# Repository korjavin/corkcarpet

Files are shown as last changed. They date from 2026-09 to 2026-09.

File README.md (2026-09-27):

# Corkcarpet — 3D-Printed Wine Cork Shower Mat

On Thingiverse: https://www.thingiverse.com/thing:7415303

A massage shower mat made from ~100 natural wine corks. The corks stand vertically inside a 3D-printed interlocking frame. Only the corks touch the floor — the plastic frame floats 5 mm above the floor, supported entirely by the corks.

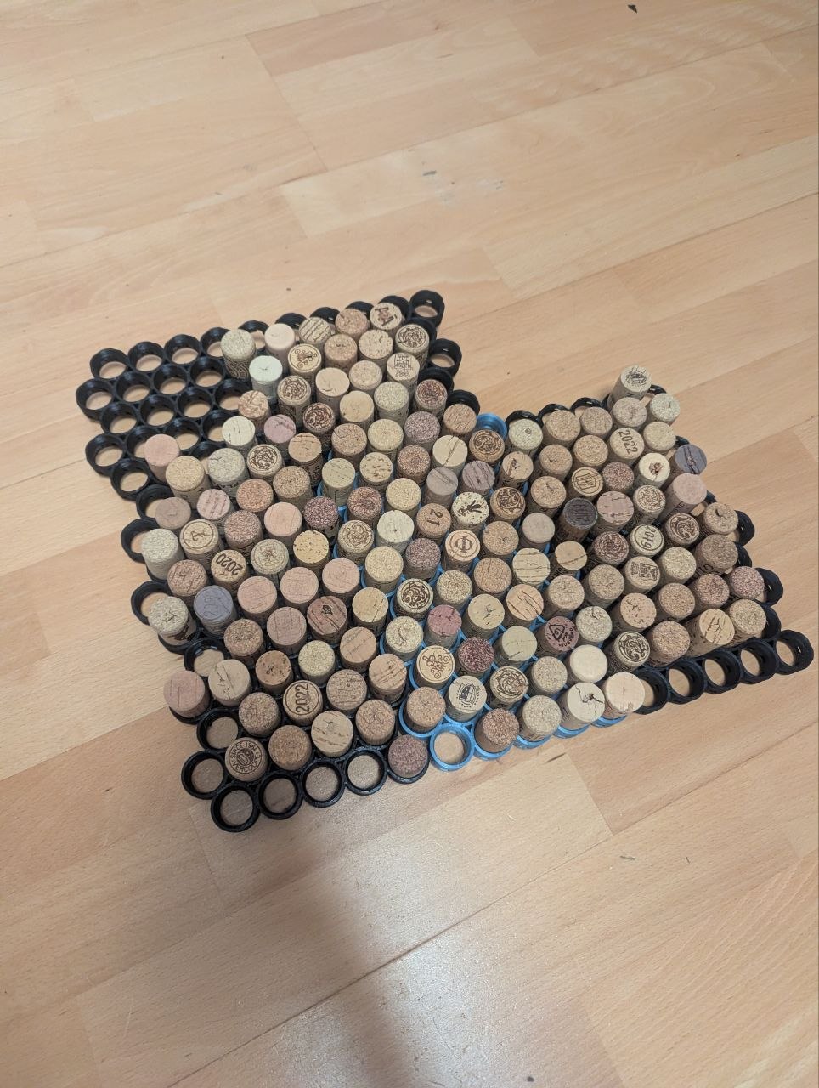
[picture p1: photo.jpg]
Assembled Corkcarpet


## What to Print

For a standard 100-cork mat (approx. 275 × 215 mm) made of 4 tiles:

| File | Quantity | Description |
|---|---|---|
| `tile_5x5_hex.stl` | 4 | 25-socket tile (137.5 × 112.6 × 15 mm, ~82 g PLA). Edge cups are trimmed along the hex cell boundary so tiles nest flush and all tunnels align perfectly. |
| `small_parts_plate.stl` | 1 | Convenience plate containing 12 dowels + 3 spacers in a single 74 × 66 mm print (~20 min). |
| *or* `dowel.stl` | 12 | 4 × 4 × 8 mm square dowel to lock tiles together (printed individually). |
| *or* `spacer.stl` | 3 | 5 mm height spacer, used only during assembly to set the bottom cork offset. |
| `dowel_thin.stl` | Optional | 8 × 3.4 × 4 mm thin dowel — use if the standard 4 × 4 dowel is too tight in your printed tunnels. |
| `dowel_wedge_x12.stl` | Optional (1) | 12 tapered wedge dowels (2 → 5 mm × 10 mm) in one print, printed lying flat. Useful if 3D-printed tunnel ceilings sag and standard square dowels fit too tightly. |

### Cork Fit Test & Training Set (print this first)

`test_tubes.stl` — 7 sockets with bore Ø18.5 … 21.5 mm in 0.5 mm steps (no supports, same orientation as the tile). A notch marks the Ø18.5 end; sizes then go up in a zigzag between the two rows: 18.5, 19.0, 19.5, 20.0, 20.5, 21.0, 21.5.

How to use it:
1. Print it with the same material and profile you will use for the tiles.
2. Press a few typical corks (narrow end down) into each socket. The right size holds the cork firmly by friction but still lets you push it through with your thumb.
3. The tiles are built with Ø20.0. If a different socket fits your corks and printer best, set `SOCKET_D` in `build_tile.py` to that value and regenerate the tile in Blender.
4. Keep the print as a sorting gauge: a cork that drops through Ø20.0 by itself is too thin, one that won't enter Ø21.5 is too thick.

**Training corks before assembly.** The same print is a cork "trainer". A fresh cork is stiff and hard to press into a Ø20 tile socket. Push it through the sockets one by one, from the widest (Ø21.5) down to Ø20.0 (or one step smaller). Each step squeezes the cork a little; after the run it slides into the tile easily and still expands enough to grip. Train a batch of corks right before you press them into the mat.

### Slicing & Printing Recommendations
- **Cura profiles**: Included in the `cura/` folder — import `cura/CorkMat_PLA_Fast.curaprofile` (or `cura/CorkMat_PETG_Fast.curaprofile` for PETG) via *Preferences → Profiles → Import*.
- **Tile orientation**: Print flat with socket entry funnels facing down (as exported). No supports needed.
- **Print order**: Print small parts first (~20 min) to test tolerances, then the tiles (~7 hrs each with Fast profile).

## Cork Selection

- **Type**: Solid, natural wine corks with a narrow end of 20–21 mm. Discard corks that are too thin (<20 mm) or too thick (>21.5 mm at the narrow end).
- **Length**: 45–49 mm is typical and works well; length variance does not affect the assembly.

## Assembly

1. **Arrange Tiles**: Place 4 tiles on a flat surface in a 2 × 2 grid. Rotate the top row of tiles by 180° so the staggered hexagonal pattern and interlocking seams mesh together.
2. **Insert Dowels**: On each of the four seams, choose 3 pairs of adjacent socket cups (e.g. both ends and the middle). At 2 mm above the bottom of the cup wall, there is a square tunnel leading into the adjacent socket. Push a 4 × 4 × 8 mm dowel through the tunnel from inside one cup until it spans both walls and protrudes ~1 mm into each socket.
3. **Place Spacers**: Slide 2–3 spacers (5 mm thick) under the frame so the plastic floats above the table.
4. **Press Corks**: Insert corks narrow end down into the socket entry funnel and press down firmly until the cork touches the table. The cork will protrude exactly 5 mm below the bottom of the frame, locking the dowels securely in place. Start with the sockets that contain dowels to lock them first.
5. **Finish**: Remove the spacers. The mat is ready to use!

## Disassembly

To separate tiles, pull out the corks from the sockets containing dowels, push the dowels out, and detach the tiles.

## Care & Maintenance

Natural cork is water-resistant and mold-resistant. Every few months, shake out the mat and let it air-dry. If an individual cork becomes loose over time, simply replace it with a slightly thicker one.

## License

CC BY 4.0 — Creative Commons Attribution 4.0 International.

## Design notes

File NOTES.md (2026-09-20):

# Corkcarpet — коврик для душа из винных пробок

Статус на 2026-09-10: калибровка сделана (PLA). SOCKET_D = 20.0 (средний из ряда трёх, штангенциркуль 20.0, принтер печатает в размер). tile_5x5.stl экспортирован с 20.0. Следующее: печать плитки из PETG.

## Идея
~100 натуральных винных пробок стоят вертикально в 3D-печатном держателе. Массажный коврик для душа:
нога стоит на пробке, пластик низко, никакой верхней плиты. Рамка ВИСИТ на пробках: пробка держится
трением узким концом вниз, проходит сквозь стакан и выступает на 5 мм НИЖЕ пластика — пола касаются
только пробки (пластик царапал поддон, пробка не скользит и не царапает). Упора нет: широкий конец
пробки сам не проходит через Ø20. Дренаж свободный, рамка над полом.

## Замеры пробок (4 шт.)
- узкий конец 20–21 мм, широкий 20–23 мм, длина 45–49 мм
- пробок много, аутлайеры отбраковываем, сортируем

## Решения
- Раскладка: гексагональная (шахматная), шаг 25 мм → зазор между пробками ~2 мм
- Плитка 5×5 = 25 гнёзд, 138.5×112.6×15 мм; 4 плитки = 100 гнёзд, коврик ~277×217 мм. Второй ряд плиток кладётся повёрнутым на 180° (нечётное число рядов), файл один.
- Стакан Ø26 снаружи, стаканы перекрываются на 1 мм (шов 7 мм) — это и есть каркас
- Стакан 15 мм: конусный заход 5 мм (Ø22.5 → Ø20) + сквозной цилиндр Ø20 на 10 мм. Без упора, без арок. Туннели 4.4×4.4 через стенки на z=2..6.4 в 3 направлениях (под шпонки).
- Материал коврика: PETG (душ, тёплая вода; PLA поведёт). Тест — на PLA, это ок.
- Принтер: Creality Ender, стол 220×220 (уточнить модель), слайсер Ultimaker Cura
- Multiboard Octagon Plate.stl — референс (решётка, фаски, идея соединителей), геометрию не берём

## Файлы
- `corkcarpet.blend` — сцена: tile, cork_* (макет пробок), test_tubes, test2_plate, test_plate, multiboard_ref
- `build_tile.py` — генератор: `build()` плитка, `build_test()` калибровка. Все размеры в шапке,
  `SOCKET_D` — посадочный диаметр, единственная неизвестная. Запуск: exec в Blender (через blender-mcp
  сокет localhost:9876, execute_code) или в текстовом редакторе Blender.
- `tile_5x5_hex.stl` — ТЕКУЩАЯ плитка (2026-09-15): как tile_5x5 + кромочные стаканы подрезаны по гексагональной ячейке (0.5 мм там, где нет соседа), 137.5 × 112.6. `build(clip=True)`.
- `tile_5x5.stl` — старая плитка без подрезки: через шов стаканы Ø26 не перекрываются, соседняя плитка отходит на 1.9 мм (зубчатый шов) / 1.15 (ровный), диагональные туннели смещены на 1.64 / 0.57 мм → шпонки не входят. Для уже напечатанных: прямые туннели на зубчатом шве + `dowel_thin.stl` 3.4 мм на ровном.
- `README.md` — инструкция по печати и сборке для пользователя
- `dowel.stl` — шпонка 4×4×8 соединения плиток (12 шт)
- `dowel_wedge.stl` / `dowel_wedge_x12.stl` (2026-09-20) — клин квадратного сечения 2×2 → 5×5, 10 мм (v2 2026-09-20: 12 мм / нос 2.5 мешала пробкам и не заходила во вторую стенку), дно ровное. Для швов старая+новая и когда обычная не лезет: печатный туннель меньше 4.4 (верх-мостик провисает) плюс увод. Носом вперёд, хвост клинится в ближней стенке (при туннеле 4.2 нос выходит на ~1.2 мм во второй стакан). Печатать лёжа. `build_dowel_wedge()`. Отвергнуты: квадратная со ступенчатым носом (не вставить), круглый конус (печать стоя).
- Старая+новая плитка на одном шве (пересчёт 2026-09-20): зубчатый шов зазор 1.0 мм, прямые туннели без увода; ровный шов зазор 0.58, диагональные туннели увод 0.29. Стыковать можно, пометка «нельзя смешивать» ниже устарела; в квадрате 2×2 швы перекосит до 1 мм.
- `spacer.stl` — подкладка 5 мм под рамку при запрессовке пробок (2–3 шт), чтобы пробки выступали снизу
- `small_parts_plate.stl` — 12 шпонок + 3 подкладки на одном столе
- `test_tubes.stl` — ТЕКУЩИЙ калибровочный тест: 7 стаканов Ø18.5…21.5 шаг 0.5, вырез сверху у 18.5
- `test_plate_compact.stl`, `test_plate_18.5-21.5.stl` — старые версии теста (брусок), не нужны

## Что проверить после печати теста
1. В какие гнёзда пробка входит рукой, в какие с трудом/не входит
2. Из каких выпадает, если перевернуть и стукнуть
3. Реальный диаметр гнёзд 19.5 и 20.5 штангенциркулем (поправка принтера)
4. Пошатать пробку вбок с усилием — не вылезает ли (рычаг 30 мм на хвате 14)
5. Мокрый тест на PLA не показателен, отложить до PETG-плитки

## Следующие шаги
- Подставить SOCKET_D по результатам (для PETG взять как на PLA или на 0.25 меньше), переэкспортировать tile
- Напечатать одну плитку из PETG, проверить с пробками, мокрый/сухой цикл, устойчивость рамки на пробках
- Соединители плиток: шпонка `dowel.stl` 4×4×8 мм. Вставляется изнутри стакана в туннель на стыке, проходит обе стенки (3+3) и на 1 мм торчит в каждый стакан; пробки её запирают. 3 на стык, 12 на коврик. Сборка: сначала шпонки, потом пробки в стаканы у стыка.
- Уточнить модель принтера: если стол 165 (Ender 2 Pro) — плитка 4×5

## Принтер и слайсер (уточнено 2026-09-10)
- Creality Ender-3 V3 SE (стол 220×220, direct drive Sprite), Cura 5.13, филамент Creality PLA
- Пользователь всегда печатает медленно и с raft/brim — старый капризный принтер. Его рабочий профиль: Ender3_Ship_SafeSlow_Raft (35 мм/с, 205/60, слой 0.16)
- Калибровочный тест печатался этим профилем → Ø20 вышел в размер; горизонтальную компенсацию не трогать
- Профили проекта: `cura/CorkMat_PLA_Raft.curaprofile`, `cura/CorkMat_PETG_Raft.curaprofile` (Cura → Preferences → Profiles → Import). Отличия от SafeSlow: слой 0.2, 4 стенки (стенка стакана 3 мм полностью сплошная), шов z сзади, PETG 235/75 + обдув 40 %
- PLA для коврика допустим: рамка висит на пробках и не нагружена, тёплая вода PLA не деформирует без нагрузки

## Ускорение печати плитки (2026-09-15)
- Факт: `petg_tile_5x5.gcode` по старому профилю = 19.9 ч, из них raft 2.4 ч, 37 600 ретрактов (760 на слой при 25 отверстиях:
  combing=infill + z-hop 0.4 на 5 мм/с ретрактили каждый переход между стенками). Нитки в отверстиях — от этих ретрактов/хопов у кромок.
- Печатаем PLA (Amazon Basics), `pla_tile_5x5.gcode` старым профилем = 16 ч. `cura/CorkMat_PLA_Fast.curaprofile` (и PETG_Fast для PETG) — оценка CuraEngine ~7 ч вместо ~16. Что изменено:
  combing=all + max comb distance 0 (сопло не сходит с пластика, на обычных слоях 0 ретрактов и 0 переездов над отверстиями),
  z-hop выкл, ретракт 1.5/40 (Sprite direct drive), слой 0.28, стенки 45/60, travel 200, raft 40 (база 20), обдув PLA 100 % / PETG 50 %.
  Не тронуто: raft, стол 75/80, первый слой 15 мм/с, 4 стенки, xy-компенсация.
- Ещё быстрее, если адгезия ок: brim 8 мм вместо raft (−45 мин), 3 стенки × 0.5 мм (−1.1 ч, Ø20 перепроверить).
- Если нитки остались: сначала сушить филамент (PLA 50 °C 4 ч), потом −5 °C.

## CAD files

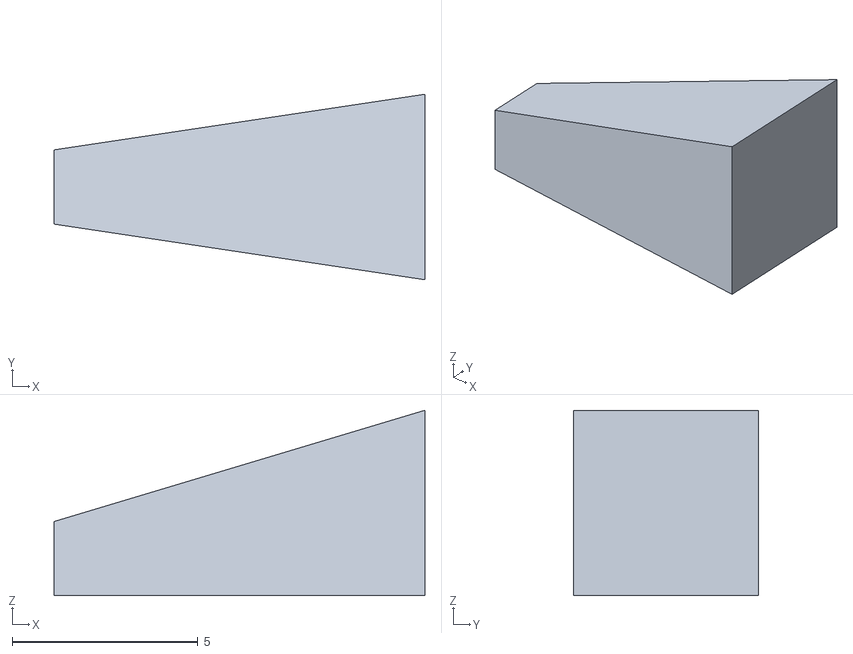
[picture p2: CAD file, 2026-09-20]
dowel_wedge.stl
10.0 x 5.00 x 5.00

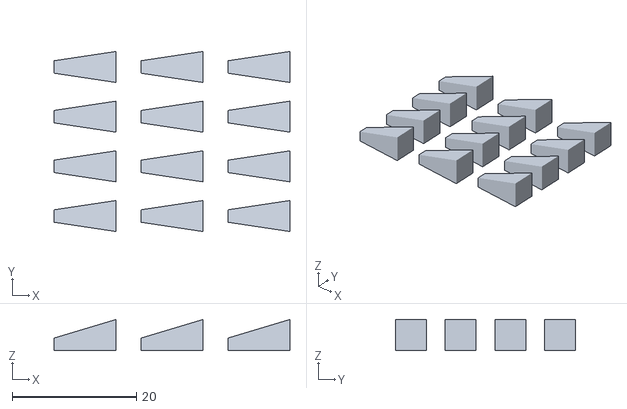
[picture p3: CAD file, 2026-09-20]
dowel_wedge_x12.stl
38.0 x 29.0 x 5.00

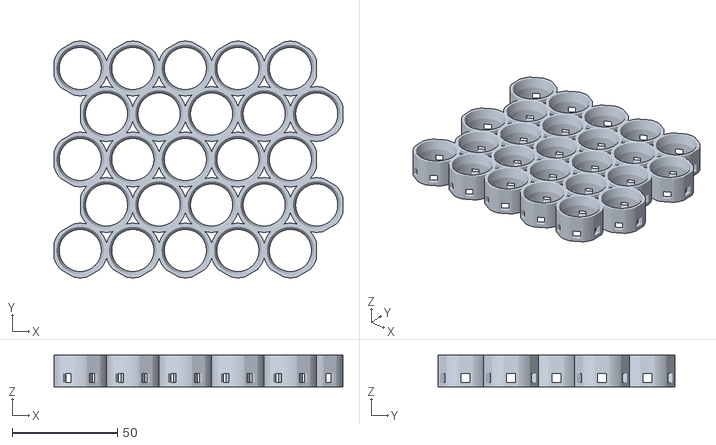
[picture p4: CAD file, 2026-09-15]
tile_5x5_hex.stl
137.5 x 112.6 x 15.0

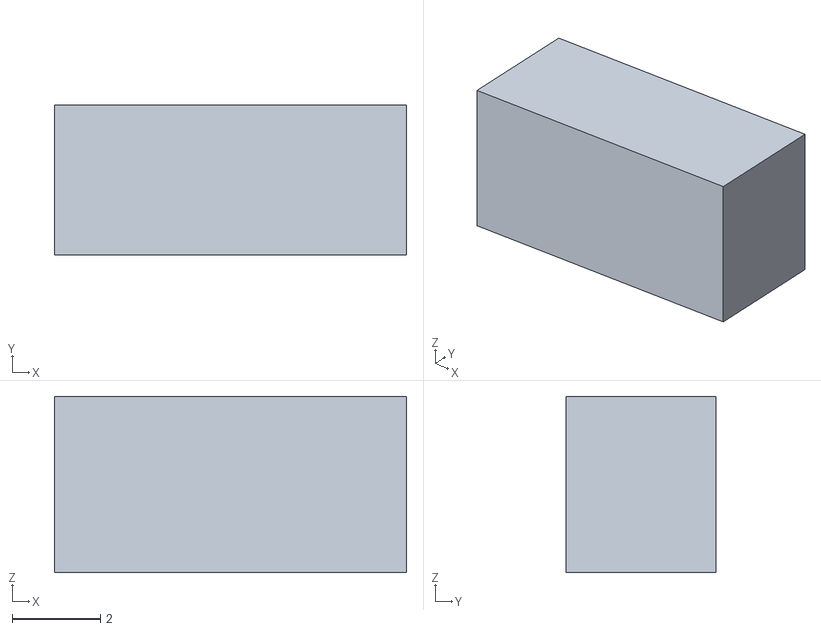
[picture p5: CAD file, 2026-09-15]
dowel_thin.stl
8.00 x 3.40 x 4.00

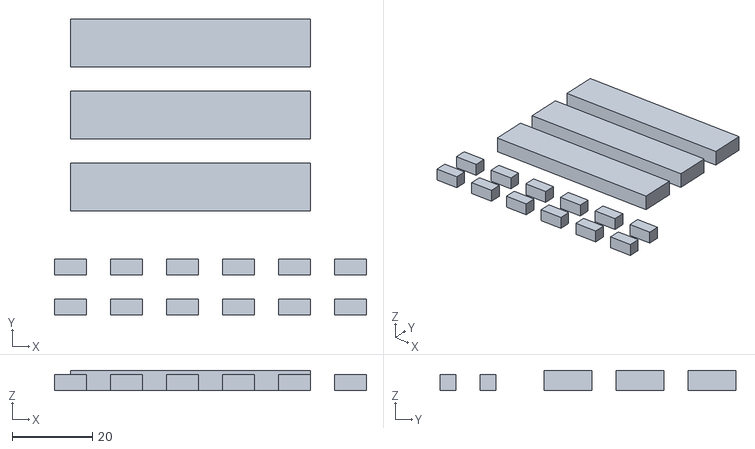
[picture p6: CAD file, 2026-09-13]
small_parts_plate.stl
78.0 x 74.0 x 5.00

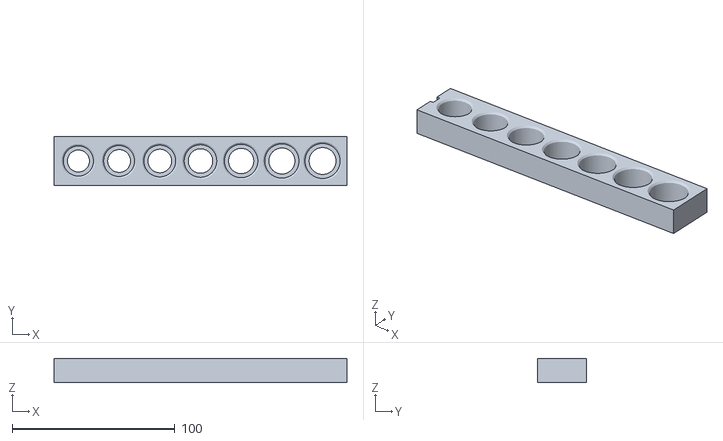
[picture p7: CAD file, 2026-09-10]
test_plate_18.5-21.5.stl
180.0 x 30.0 x 15.0

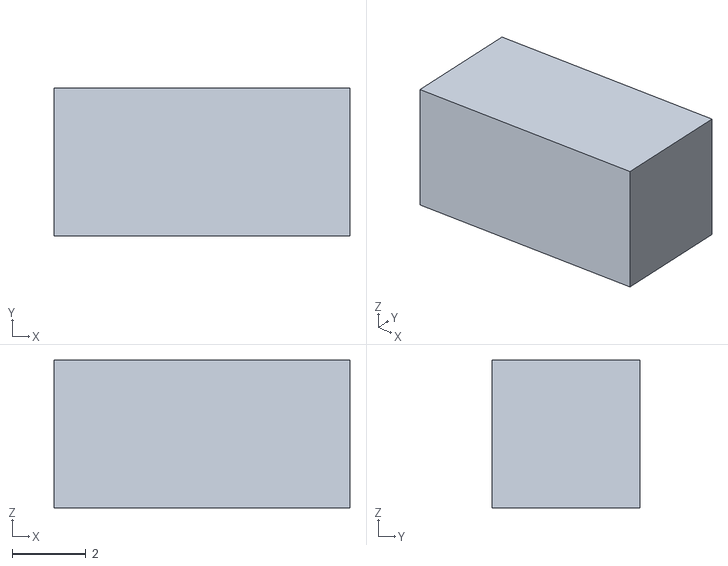
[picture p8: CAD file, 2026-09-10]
dowel.stl
8.00 x 4.00 x 4.00

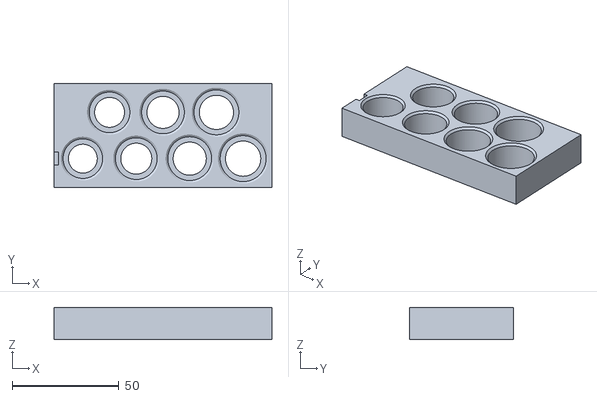
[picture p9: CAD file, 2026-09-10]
test_plate_compact.stl
102.0 x 48.7 x 15.0

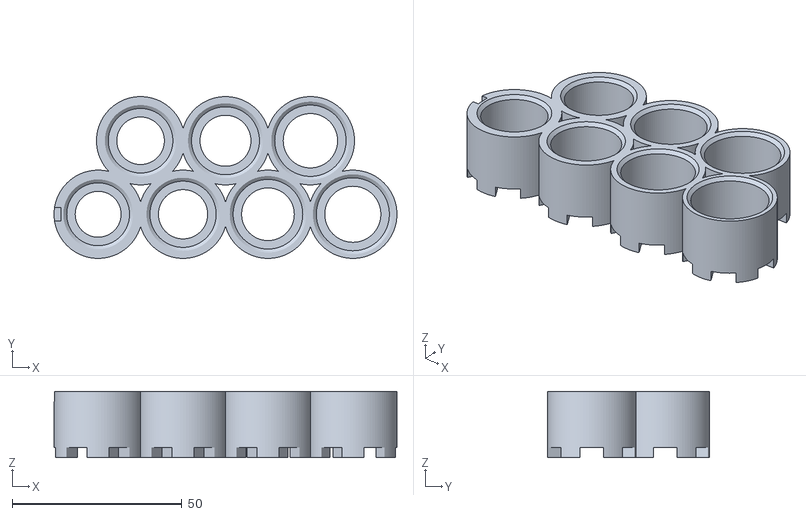
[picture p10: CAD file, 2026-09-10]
test_tubes.stl
101.0 x 47.7 x 19.5

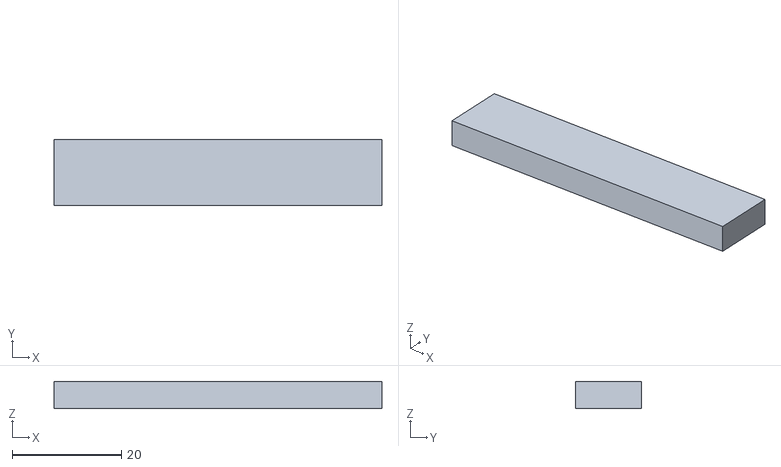
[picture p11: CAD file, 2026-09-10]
spacer.stl
60.0 x 12.0 x 5.00

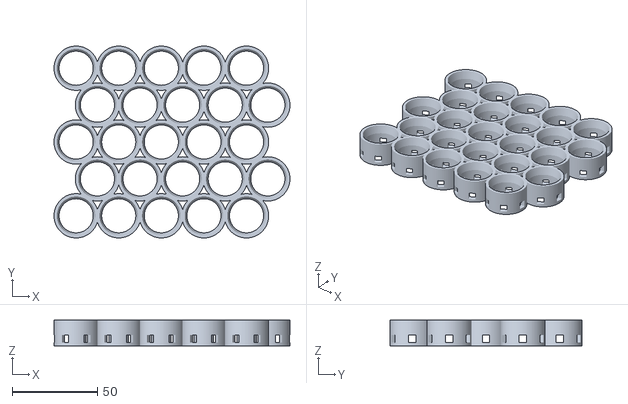
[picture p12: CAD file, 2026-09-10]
tile_5x5.stl
138.5 x 112.6 x 15.0

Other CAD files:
corkcarpet.blend

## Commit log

2026-09-10 Initial commit: calibration models, unclipped 5x5 tile and Cura raft profiles
    [dowel.stl, spacer.stl, test_plate_18.5-21.5.stl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]
2026-09-13 Add Blender scene and combined small parts plate STL
    [corkcarpet.blend, small_parts_plate.stl]
2026-09-15 Add clipped tile (tile_5x5_hex), dowel_thin, and Fast Cura profiles
    [dowel_thin.stl, tile_5x5_hex.stl]
2026-09-20 Add wedge dowels, Blender parametric script, assembly guide and project notes
    [dowel_wedge.stl, dowel_wedge_x12.stl]
2026-09-24 Add photo of assembled corkcarpet and include it in README
2026-09-27 Document cork fit test (test_tubes.stl)
2026-09-27 README: drop print-time guess
